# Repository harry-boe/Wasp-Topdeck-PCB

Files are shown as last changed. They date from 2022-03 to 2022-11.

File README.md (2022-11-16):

# Wasp-Topdeck-PCB

This is the pcb to simplyfy the wireing for the WASP IDEX 3d printer

The printer is a variation of the Double Dragon from zrancho

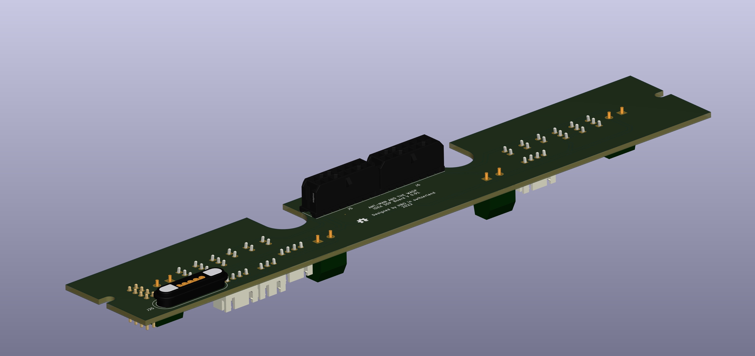
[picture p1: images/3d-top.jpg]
top


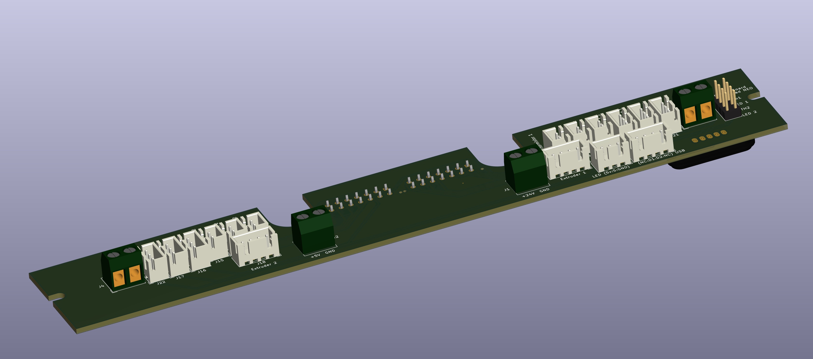
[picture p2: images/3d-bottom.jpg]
bottom


Connectors are common JST, Molex and Terminals with the exception
of a 5 pin magnetic connector for wirening the tophead USB cam and LED's

The connector can be sourced from Aliexpress here https://www.aliexpress.com/item/1005003238190621.html

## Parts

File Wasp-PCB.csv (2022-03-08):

Source: | /Users/Harry/Develop/3d-Print/harry-boe/Wasp-Topdeck-PCB/Wasp-PCB.kicad_sch
Date: | 2022 March 08, Tuesday 13:42:42
Tool: | Eeschema (6.0.2-0)
Generator: | /Applications/KiCad/KiCad.app/Contents/SharedSupport/plugins/bom_csv_grouped_by_value_with_fp.py
Component Count: | 24
Ref | Qnty | Value | Cmp name | Footprint | Description | Vendor
J1, | 1 | 24V_VCC | Screw_Terminal_01x02 | TerminalBlock_RND:TerminalBlock_RND_205-00001_1x02_P5.00mm_Horizontal | Generic screw terminal, single row, 01x02, script generated (kicad-library-utils/schlib/autogen/connector/)
J2, | 1 | 5V_VCC | Screw_Terminal_01x02 | TerminalBlock_RND:TerminalBlock_RND_205-00001_1x02_P5.00mm_Horizontal | Generic screw terminal, single row, 01x02, script generated (kicad-library-utils/schlib/autogen/connector/)
J3, | 1 | HEATER_1 | Screw_Terminal_01x02 | TerminalBlock_RND:TerminalBlock_RND_205-00001_1x02_P5.00mm_Horizontal | Generic screw terminal, single row, 01x02, script generated (kicad-library-utils/schlib/autogen/connector/)
J4, | 1 | HEATER_2 | Screw_Terminal_01x02 | TerminalBlock_RND:TerminalBlock_RND_205-00001_1x02_P5.00mm_Horizontal | Generic screw terminal, single row, 01x02, script generated (kicad-library-utils/schlib/autogen/connector/)
J5, | 1 | Toolhead_1 | Conn_02x07_Counter_Clockwise | Connector_Molex:Molex_Micro-Fit_3.0_43045-1412_2x07_P3.00mm_Vertical | Generic connector, double row, 02x07, counter clockwise pin numbering scheme (similar to DIP packge numbering), script generated (kicad-library-utils/schlib/autogen/connector/)
J6, | 1 | Toolhead_2 | Conn_02x07_Counter_Clockwise | Connector_Molex:Molex_Micro-Fit_3.0_43045-1412_2x07_P3.00mm_Vertical | Generic connector, double row, 02x07, counter clockwise pin numbering scheme (similar to DIP packge numbering), script generated (kicad-library-utils/schlib/autogen/connector/)
J7, J13, | 2 | Thermistor_1 | Conn_02x01 | Connector_JST:JST_XH_B2B-XH-A_1x02_P2.50mm_Vertical | Generic connector, double row, 02x01, this symbol is compatible with counter-clockwise, top-bottom and odd-even numbering schemes., script generated (kicad-library-utils/schlib/autogen/connector/)
J8, J14, | 2 | Fan_Parts_1 | Conn_02x01 | Connector_JST:JST_XH_B2B-XH-A_1x02_P2.50mm_Vertical | Generic connector, double row, 02x01, this symbol is compatible with counter-clockwise, top-bottom and odd-even numbering schemes., script generated (kicad-library-utils/schlib/autogen/connector/)
J9, J15, | 2 | Fan_Hotend_1 | Conn_02x01 | Connector_JST:JST_XH_B2B-XH-A_1x02_P2.50mm_Vertical | Generic connector, double row, 02x01, this symbol is compatible with counter-clockwise, top-bottom and odd-even numbering schemes., script generated (kicad-library-utils/schlib/autogen/connector/)
J10, | 1 | Y_Endstop_1 | Conn_01x03 | Connector_JST:JST_XH_B3B-XH-A_1x03_P2.50mm_Vertical | Generic connector, single row, 01x03, script generated (kicad-library-utils/schlib/autogen/connector/)
J11, | 1 | Z_Endstop_1 | Conn_01x03 | Connector_JST:JST_XH_B3B-XH-A_1x03_P2.50mm_Vertical | Generic connector, single row, 01x03, script generated (kicad-library-utils/schlib/autogen/connector/)
J12, | 1 | Extruder_1 | Conn_01x04 | Connector_JST:JST_XH_B4B-XH-A_1x04_P2.50mm_Vertical | Generic connector, single row, 01x04, script generated (kicad-library-utils/schlib/autogen/connector/)
J16, | 1 | Y_Endstop_2 | Conn_01x03 | Connector_JST:JST_XH_B3B-XH-A_1x03_P2.50mm_Vertical | Generic connector, single row, 01x03, script generated (kicad-library-utils/schlib/autogen/connector/)
J17, | 1 | Z_Endstop_2 | Conn_01x03 | Connector_JST:JST_XH_B3B-XH-A_1x03_P2.50mm_Vertical | Generic connector, single row, 01x03, script generated (kicad-library-utils/schlib/autogen/connector/)
J18, | 1 | Extruder_2 | Conn_01x04 | Connector_JST:JST_XH_B4B-XH-A_1x04_P2.50mm_Vertical | Generic connector, single row, 01x04, script generated (kicad-library-utils/schlib/autogen/connector/)
J19, | 1 | Conn_02x04_Odd_Even | Conn_02x04_Odd_Even | Connector_PinHeader_2.54mm:PinHeader_2x04_P2.54mm_Vertical | Generic connector, double row, 02x04, odd/even pin numbering scheme (row 1 odd numbers, row 2 even numbers), script generated (kicad-library-utils/schlib/autogen/connector/)
J21, | 1 | Neopixel_T1 | Conn_01x03 | Connector_JST:JST_XH_B3B-XH-A_1x03_P2.50mm_Vertical | Generic connector, single row, 01x03, script generated (kicad-library-utils/schlib/autogen/connector/)
J22, | 1 | Neopixel_T2 | Conn_01x03 | Connector_JST:JST_XH_B3B-XH-A_1x03_P2.50mm_Vertical | Generic connector, single row, 01x03, script generated (kicad-library-utils/schlib/autogen/connector/)
J23, | 1 | Neopixel_F1 | Conn_01x03 | Connector_JST:JST_XH_B3B-XH-A_1x03_P2.50mm_Vertical | Generic connector, single row, 01x03, script generated (kicad-library-utils/schlib/autogen/connector/)
J24, | 1 | USB_CAM | Conn_01x04 | Connector_JST:JST_XH_B4B-XH-A_1x04_P2.50mm_Vertical | Generic connector, single row, 01x04, script generated (kicad-library-utils/schlib/autogen/connector/)
J25, | 1 | TopHead_1 | Conn_01x05 | Wasp-Board:Connector_Mag_05x_2.0mm | Generic connector, single row, 01x05, script generated (kicad-library-utils/schlib/autogen/connector/)

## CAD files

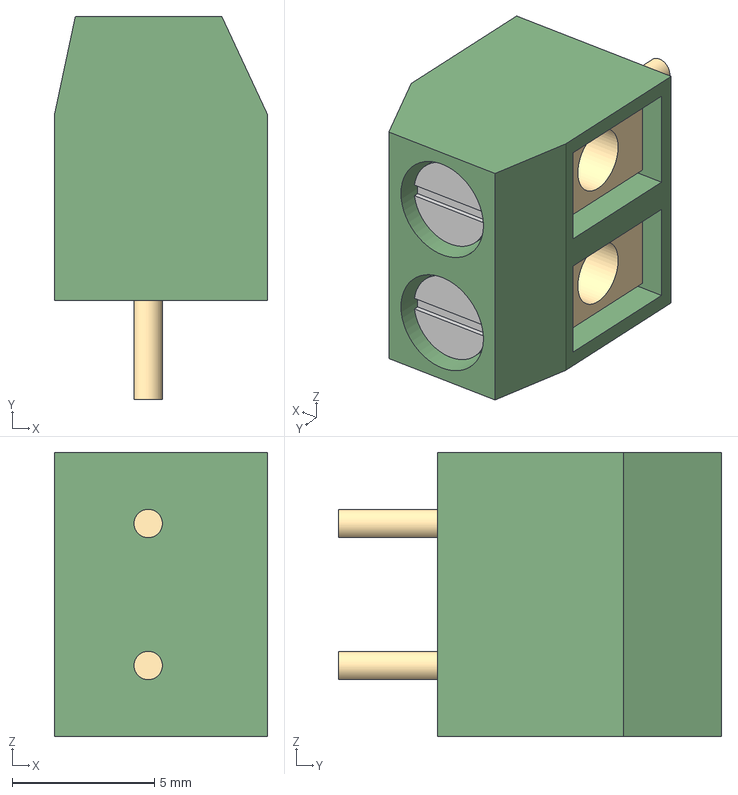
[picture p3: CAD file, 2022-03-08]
3dmodels/Terminal_5mm_02x_Vertical.step
7.50 x 13.5 x 10.0 mm

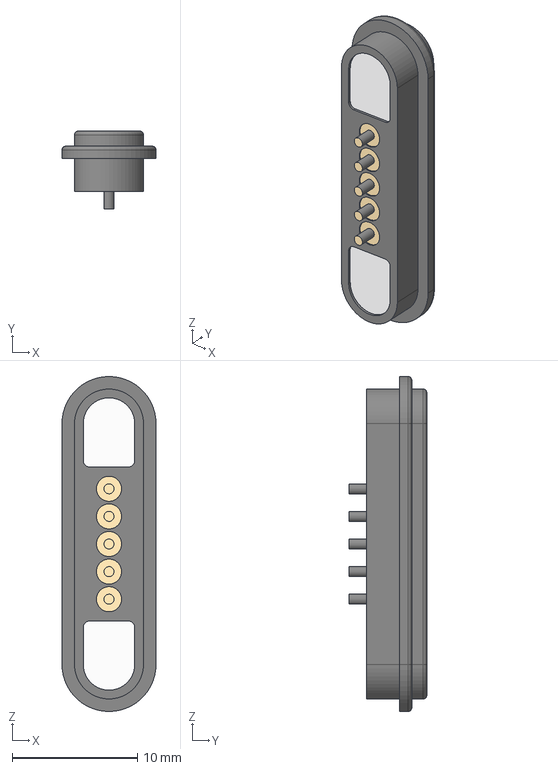
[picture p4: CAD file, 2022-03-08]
3dmodels/Connector_05x_Mag.step
7.50 x 6.20 x 26.7 mm

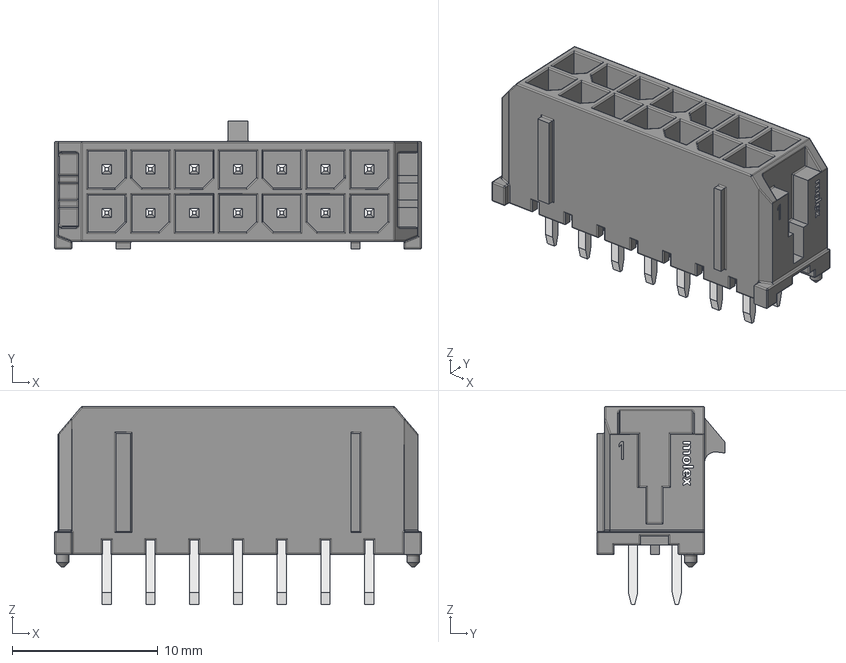
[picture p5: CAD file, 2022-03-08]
3dmodels/Molex_Micro-Fit_3.0_43045-1412_2x07_P3.00mm_Vertical.step
25.1 x 8.77 x 13.6 mm
Leads
Logo

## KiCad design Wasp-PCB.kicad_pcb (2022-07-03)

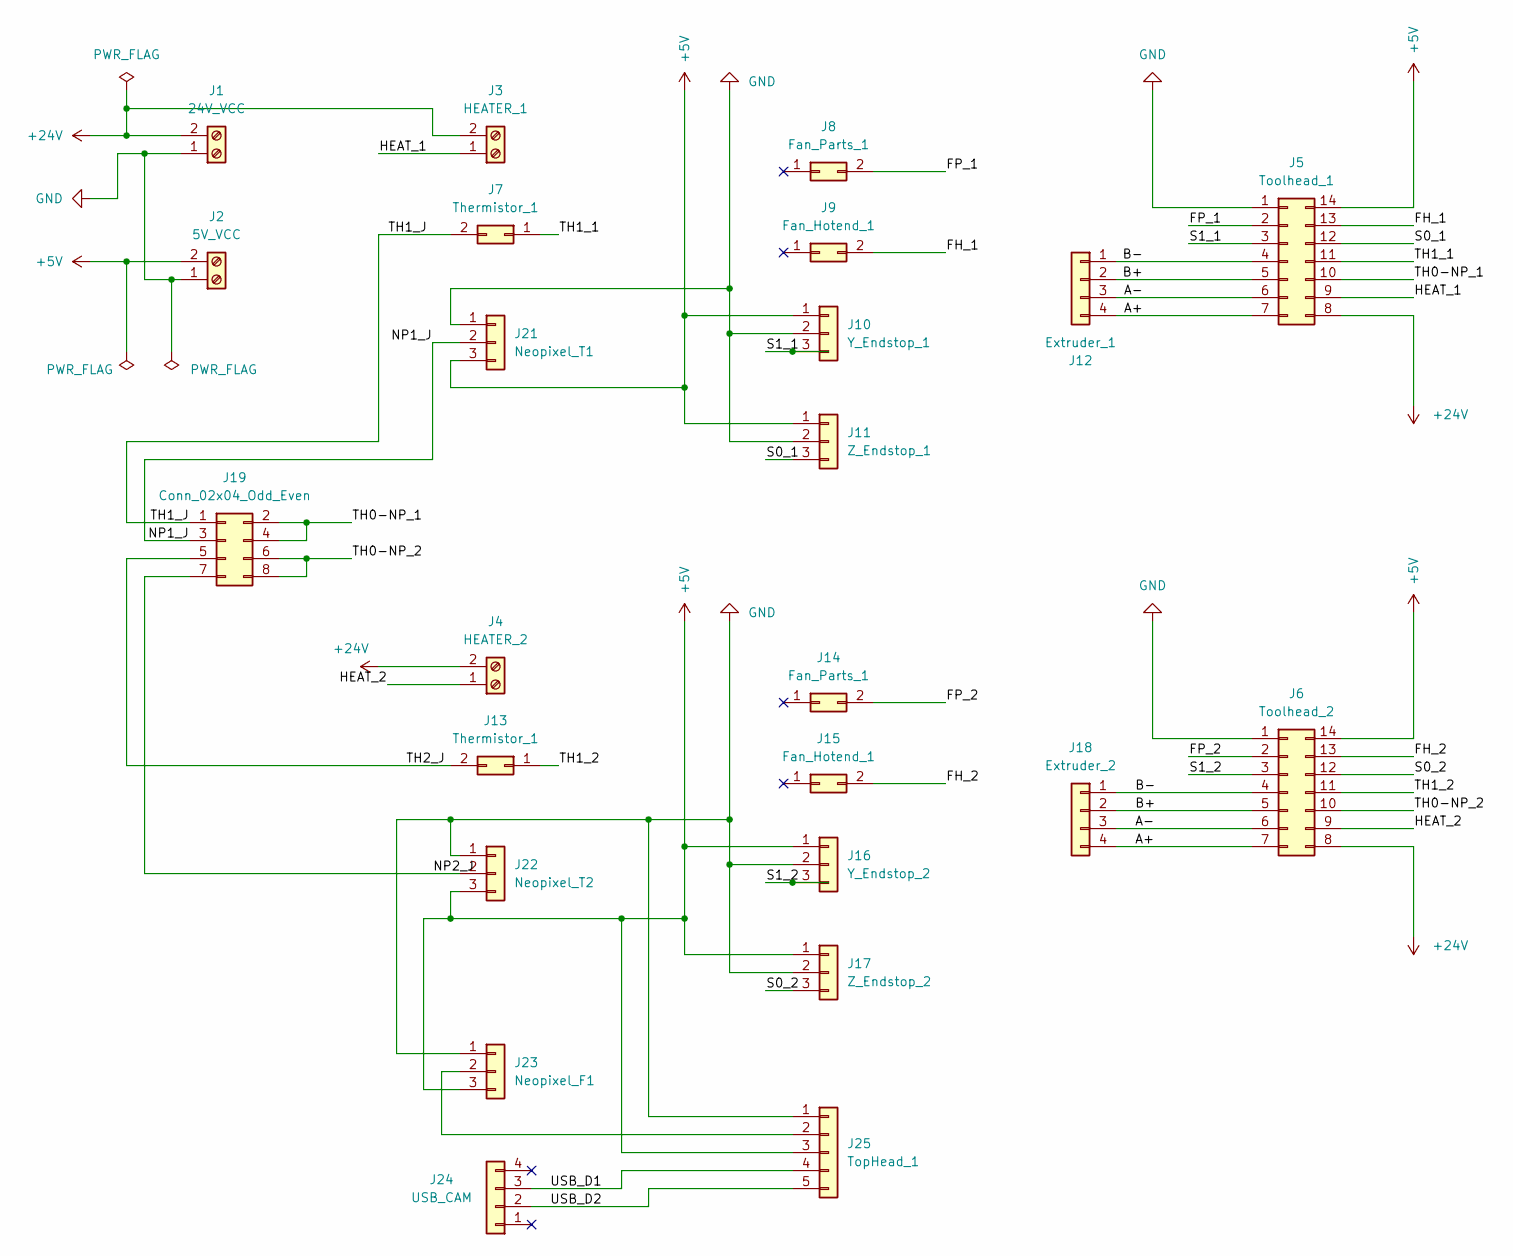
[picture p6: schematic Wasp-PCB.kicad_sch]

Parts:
J1: 24V_VCC; TerminalBlock_RND_205-00001_1x02_P5.00mm_Horizontal
J2: 5V_VCC; TerminalBlock_RND_205-00001_1x02_P5.00mm_Horizontal
J3: HEATER_1; TerminalBlock_RND_205-00001_1x02_P5.00mm_Horizontal
J4: HEATER_2; TerminalBlock_RND_205-00001_1x02_P5.00mm_Horizontal
J5: Toolhead_1; Molex_Micro-Fit_3.0_43045-1412_2x07_P3.00mm_Vertical
J6: Toolhead_2; Molex_Micro-Fit_3.0_43045-1412_2x07_P3.00mm_Vertical
J7, J13: Thermistor_1; JST_XH_B2B-XH-A_1x02_P2.50mm_Vertical
J8, J14: Fan_Parts_1; JST_XH_B2B-XH-A_1x02_P2.50mm_Vertical
J9, J15: Fan_Hotend_1; JST_XH_B2B-XH-A_1x02_P2.50mm_Vertical
J10: Y_Endstop_1; JST_XH_B3B-XH-A_1x03_P2.50mm_Vertical
J11: Z_Endstop_1; JST_XH_B3B-XH-A_1x03_P2.50mm_Vertical
J12: Extruder_1; JST_XH_B4B-XH-A_1x04_P2.50mm_Vertical
J16: Y_Endstop_2; JST_XH_B3B-XH-A_1x03_P2.50mm_Vertical
J17: Z_Endstop_2; JST_XH_B3B-XH-A_1x03_P2.50mm_Vertical
J18: Extruder_2; JST_XH_B4B-XH-A_1x04_P2.50mm_Vertical
J19: Conn_02x04_Odd_Even; PinHeader_2x04_P2.54mm_Vertical
J21: Neopixel_T1; JST_XH_B3B-XH-A_1x03_P2.50mm_Vertical
J22: Neopixel_T2; JST_XH_B3B-XH-A_1x03_P2.50mm_Vertical
J23: Neopixel_F1; JST_XH_B3B-XH-A_1x03_P2.50mm_Vertical
J24: USB_CAM; JST_XH_B4B-XH-A_1x04_P2.50mm_Vertical
J25: TopHead_1; Connector_Mag_05x_2.0mm

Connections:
+5V: J2.2, J5.14, J6.14, J10.1, J11.1, J16.1, J17.1, J21.3, J22.3, J23.3, J25.3
+24V: J1.2, J3.2, J4.2, J5.8, J6.8
/A+: J5.7, J6.7, J12.4, J18.4
/A-: J5.6, J6.6, J12.3, J18.3
/B+: J5.5, J6.5, J12.2, J18.2
/B-: J5.4, J6.4, J12.1, J18.1
/FH_1: J5.13, J9.2
/FH_2: J6.13, J15.2
/FP_1: J5.2, J8.2
/FP_2: J6.2, J14.2
/HEAT_1: J3.1, J5.9
/HEAT_2: J4.1, J6.9
/NP1_J: J19.3, J21.2
/NP2_J: J19.7, J22.2
/S0_1: J5.12, J11.3
/S0_2: J6.12, J17.3
/S1_1: J5.3, J10.3
/S1_2: J6.3, J16.3
/TH0-NP_1: J5.10, J19.2, J19.4
/TH0-NP_2: J6.10, J19.6, J19.8
/TH1_1: J5.11, J7.1
/TH1_2: J6.11, J13.1
/TH1_J: J7.2, J19.1
/TH2_J: J13.2, J19.5
/USB_D1: J24.3, J25.4
/USB_D2: J24.2, J25.5
GND: J1.1, J2.1, J5.1, J6.1, J10.2, J11.2, J16.2, J17.2, J21.1, J22.1, J23.1, J25.1
unnamed: J23.2, J25.2

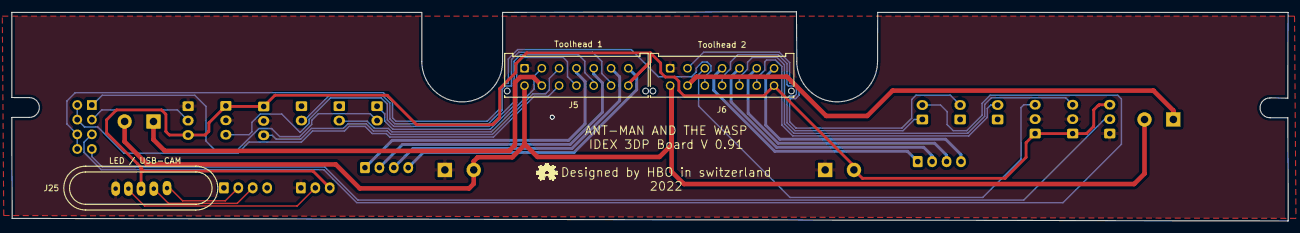
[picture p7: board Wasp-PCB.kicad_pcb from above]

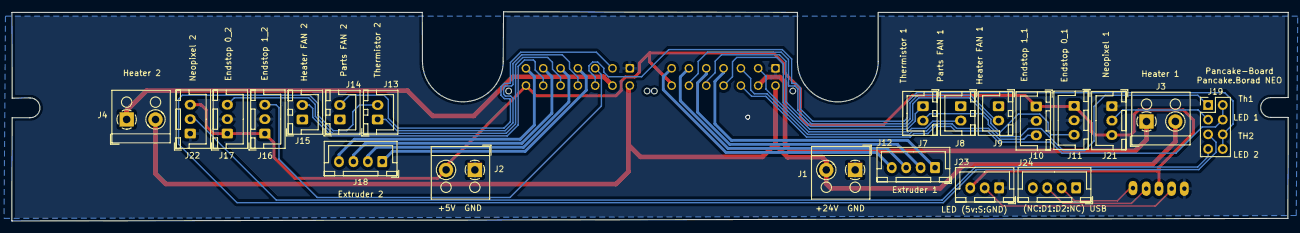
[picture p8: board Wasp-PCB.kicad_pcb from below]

Board: 2 copper layers, 221.2 x 36.2 mm, 24 parts (21 on the bottom side), 28 nets.

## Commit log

2022-03-08 initial upload KiCAD files
2022-03-08 KiCAD files added
    [Connector_05x_Mag.step, Molex_Micro-Fit_3.0_43045-1412_2x07_P3.00mm_Vertical.step, Terminal_5mm_02x_Vertical.step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]
2022-03-08 generated gerber files added
    [Wasp-PCB-B_Cu.gbr, Wasp-PCB-B_Mask.gbr, Wasp-PCB-B_Silkscreen.gbr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]
2022-07-03 V0.91 changed outline to create clearence for A/B belt tentioners updated readme
2022-07-03 added immages
    [Wasp-PCB.kicad_pcb]
2022-07-03 gerber files created / updated
    [Wasp-PCB-B_Cu.gbr, Wasp-PCB-B_Mask.gbr, Wasp-PCB-B_Silkscreen.gbr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]
